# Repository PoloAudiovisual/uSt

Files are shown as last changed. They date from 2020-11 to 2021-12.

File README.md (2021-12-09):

Front panel, gerbers, BOM and schematics for **[μSt](https://www.olivellamodular.com/ust.html), an Eurorack synthesizer module from [Olivella Modular](https://www.olivellamodular.com/)**.

Based on [Nearness](https://github.com/sarnesjo/nearness), by Jesper Särnesjö. Through-hole remix by Kevin Olivella.

WARNING !!!1!11
=======

For this design I used new-old-stock SMK jacks, almost identical to the [PJ3410](https://www.thonk.co.uk/shop/pj3410/) BUT they have different pinouts. You'll have to adapt them as following:

adapt

License
=======

[CC BY-SA 4.0][cc-by-sa].

[][cc-by-sa]

[cc-by-sa]: http://creativecommons.org/licenses/by-sa/4.0/
[cc-by-sa-image]: https://licensebuttons.net/l/by-sa/4.0/88x31.png
[cc-by-sa-shield]: https://img.shields.io/badge/License-CC%20BY--SA%204.0-lightgrey.svg

CC BY-SA 4.0 does not confer the right to use intellectual property such as trademarks, brand names, and logos. Olivella Modular, μSt and Nearness are trademarks of their respective owners and should not be used without permission.

By Kevin Olivella (kev.olivella@gmail.com)

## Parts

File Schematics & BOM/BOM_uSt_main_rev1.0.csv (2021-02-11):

ID | Name | Designator | Footprint | Quantity | Manufacturer Part | Manufacturer | Supplier | Supplier Part
1 | 100k | R15,R16,R17,R20,R21,R22,R14,R1,R23,R24 | RESISTOR_TTH_VERT_3MM | 10 | ?
2 | 1k | R18,R19 | RESISTOR_TTH_VERT_3MM | 2 | ?
3 | 1.5M | R13,R2 | RESISTOR_TTH_VERT_3MM | 2 | ?
4 | 102k | R12,R3 | RESISTOR_TTH_VERT_3MM | 2 | ?
5 | 430k | R11,R4 | RESISTOR_TTH_VERT_3MM | 2 | ?
6 | 113k | R10,R5 | RESISTOR_TTH_VERT_3MM | 2 | ?
7 | 220k | R9,R6 | RESISTOR_TTH_VERT_3MM | 2 | ?
8 | 130k | R8,R7 | RESISTOR_TTH_VERT_3MM | 2 | ?
9 | 22pF | C1,C2 | CAP-CT4-0805-5.08MM | 2 | CT4-0805B102K500F3 | Guangdong Fenghua Advanced Tech | LCSC | C192448
10 | 100nF | C8,C7,C6,C5 | CAP-CT4-0805-5.08MM | 4 | CT4-0805B102K500F3 | Guangdong Fenghua Advanced Tech | LCSC | C192448
11 | M05X2 | JP1 | 2X5-SHROUDED | 1 | ?
12 | 22uF | C4,C3 | CAP-D6.3XF2.5 | 2 | ?
13 | 2743001111 | L2,L1 | AXIAL-L-4.7X3.5 | 2
14 | PAD | H3 | HDR-F-2.54_1X4 | 1 |  |  | LCSC | C225501
15 | Header1 | H1,H2 | HDR-6X1/2.54 | 2 | Female header 1*6p | BOOMELE | LCSC | C40877
16 | 1N5819 | D2,D1 | DO-41 | 2 | 1N5819 | STARSEA | LCSC | C84620
17 | TL072 | U1,U2 | DIP-8 | 2

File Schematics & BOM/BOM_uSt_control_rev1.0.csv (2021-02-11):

ID | Name | Designator | Footprint | Quantity | Manufacturer Part | Manufacturer | Supplier | Supplier Part
1 | OUT_1 | J1 | PJ-3410, JAPAN | 1 | 9131052 | RS-Pro |  | 9131052
2 | IN_1 | J2 | PJ-3410, JAPAN | 1 | 9131052 | RS-Pro |  | 9131052
3 | IN_2 | J3 | PJ-3410, JAPAN | 1 | 9131052 | RS-Pro |  | 9131052
4 | IN_3 | J4 | PJ-3410, JAPAN | 1 | 9131052 | RS-Pro |  | 9131052
5 | IN_4 | J5 | PJ-3410, JAPAN | 1 | 9131052 | RS-Pro |  | 9131052
6 | IN_7 | J8 | PJ-3410, JAPAN | 1 | 9131052 | RS-Pro |  | 9131052
7 | IN_6 | J7 | PJ-3410, JAPAN | 1 | 9131052 | RS-Pro |  | 9131052
8 | IN_5 | J6 | PJ-3410, JAPAN | 1 | 9131052 | RS-Pro |  | 9131052
9 | OUT_2 | J9 | PJ-3410, JAPAN | 1 | 9131052 | RS-Pro |  | 9131052
10 | PAD_L | SW1 | MTS-102 | 1 |  |  | Tayda
11 | PAD_R | SW2 | MTS-102 | 1 |  |  | Tayda
12 | PAD | H3 | HDR-F-2.54_1X4 | 1 |  |  | LCSC | C225501
13 | Header1 | H1,H2 | HDR-6X1/2.54 | 2 | Female header 1*6p | BOOMELE | LCSC | C40877

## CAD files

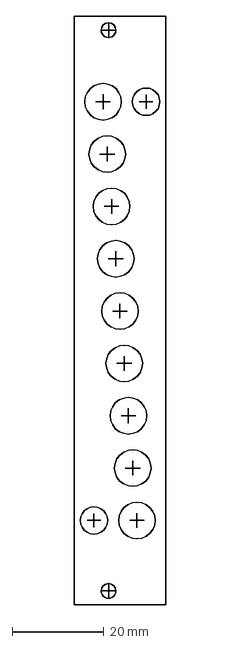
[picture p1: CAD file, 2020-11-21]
Front panel/uSt_CNC.dxf
20.0 x 128.5 mm

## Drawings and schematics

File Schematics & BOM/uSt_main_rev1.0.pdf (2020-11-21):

+12V

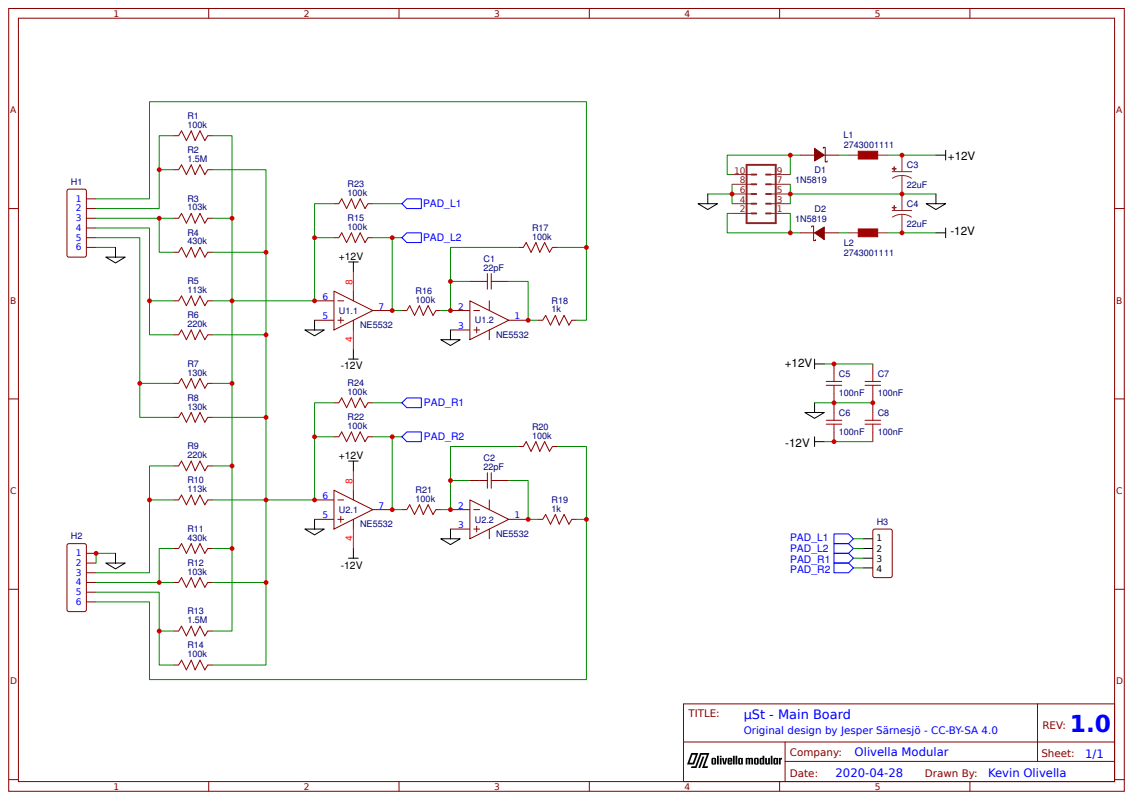
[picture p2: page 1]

Original design by Jesper Särnesjö - CC-BY-SA 4.0

Drawn By: Kevin Olivella

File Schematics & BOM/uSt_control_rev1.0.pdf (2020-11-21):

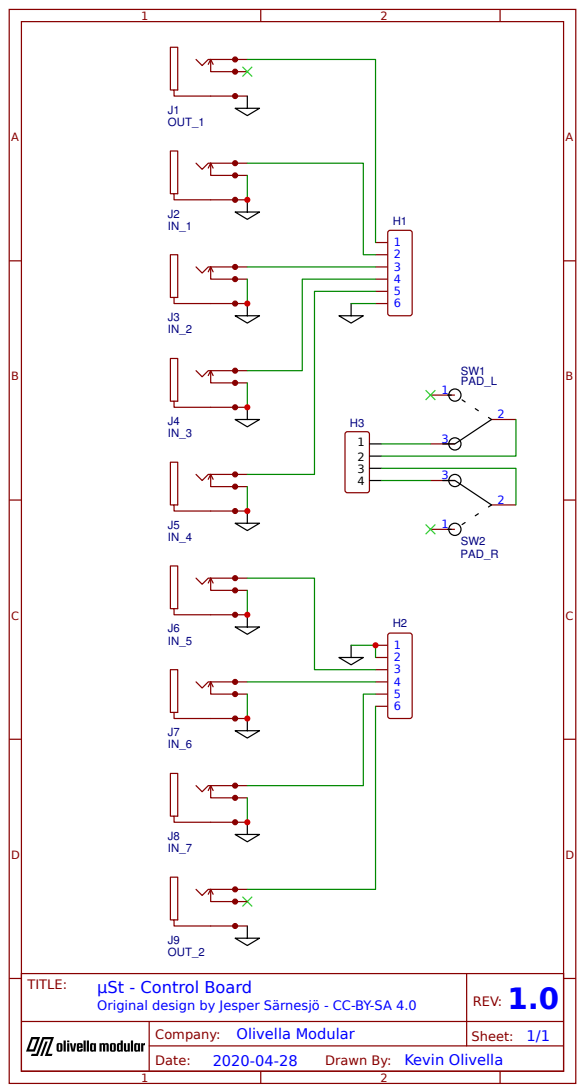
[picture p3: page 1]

Original design by Jesper Särnesjö - CC-BY-SA 4.0

Drawn By: Kevin Olivella
